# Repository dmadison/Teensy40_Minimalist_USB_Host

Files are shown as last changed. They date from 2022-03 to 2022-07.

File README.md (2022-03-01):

# Teensy 4.0 Minimalist USB Host Shield

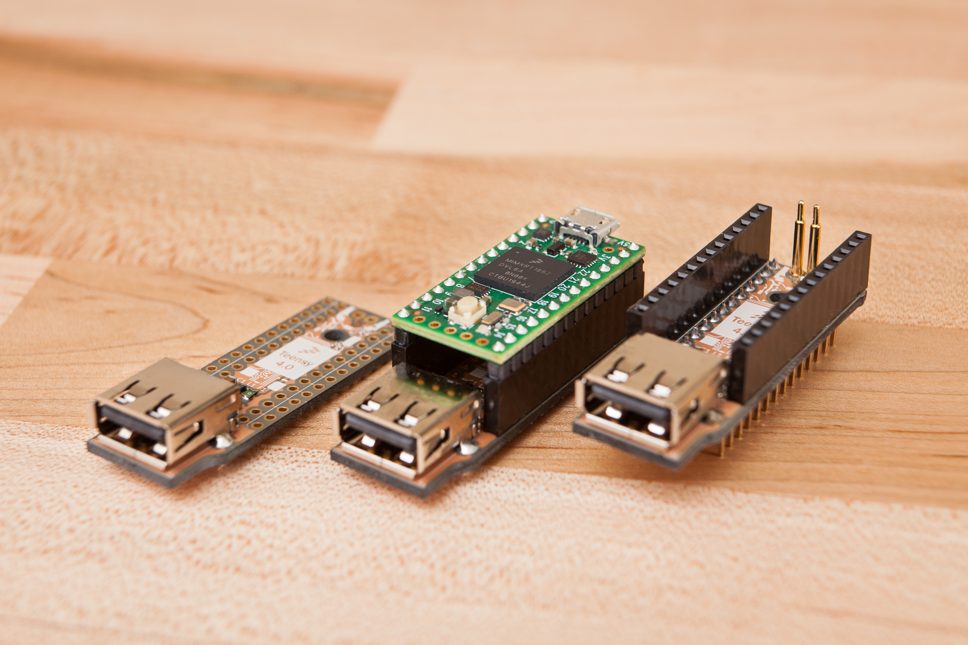
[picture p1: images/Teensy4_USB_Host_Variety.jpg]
Variations of the Teensy 4.0 Minimalist USB Host Shield, v1.0.0


This repository contains the KiCAD 6 board files for the [Teensy 4.0 minimalist USB host shield](https://www.partsnotincluded.com/teensy-4-0-minimalist-usb-host-shield). The shield is designed to connect to the underside of the Teensy 4.0 board and provide a safe and stable USB-A host port in a small and lightweight size.

The Teensy board needs to be soldered to 0.1" male headers. It can then be mated to the shield with 0.1" female headers and pogo pins, or soldered directly using enamel wire to connect to the data pads on the underside of the board.

For pogo pins, see the [PJRC Teensy 4.0 breakout board](https://www.pjrc.com/breakout-board-for-teensy-4-0/) page for reference. For my own boards I used 12 mm pogo pins purchased from RTLECS on AliExpress.

Generated gerbers and bill of materials can be found on the [releases](../../releases/latest) page.

## License

The KiCAD project files including the schematic, PCB design, symbols, and most footprints are released in the public domain with no rights reserved.

The [Parts Not Included](https://www.partsnotincluded.com/) logo, included on the bottom of the shield, is copyrighted. It may be reproduced as a silkscreen graphic in this project and its derivatives without modification.

Included images are licensed under the [CC BY-NC-ND 4.0 license](https://creativecommons.org/licenses/by-nc-nd/4.0/). Attribution should be to Dave Madison ([@dmadison](https://github.com/dmadison)).

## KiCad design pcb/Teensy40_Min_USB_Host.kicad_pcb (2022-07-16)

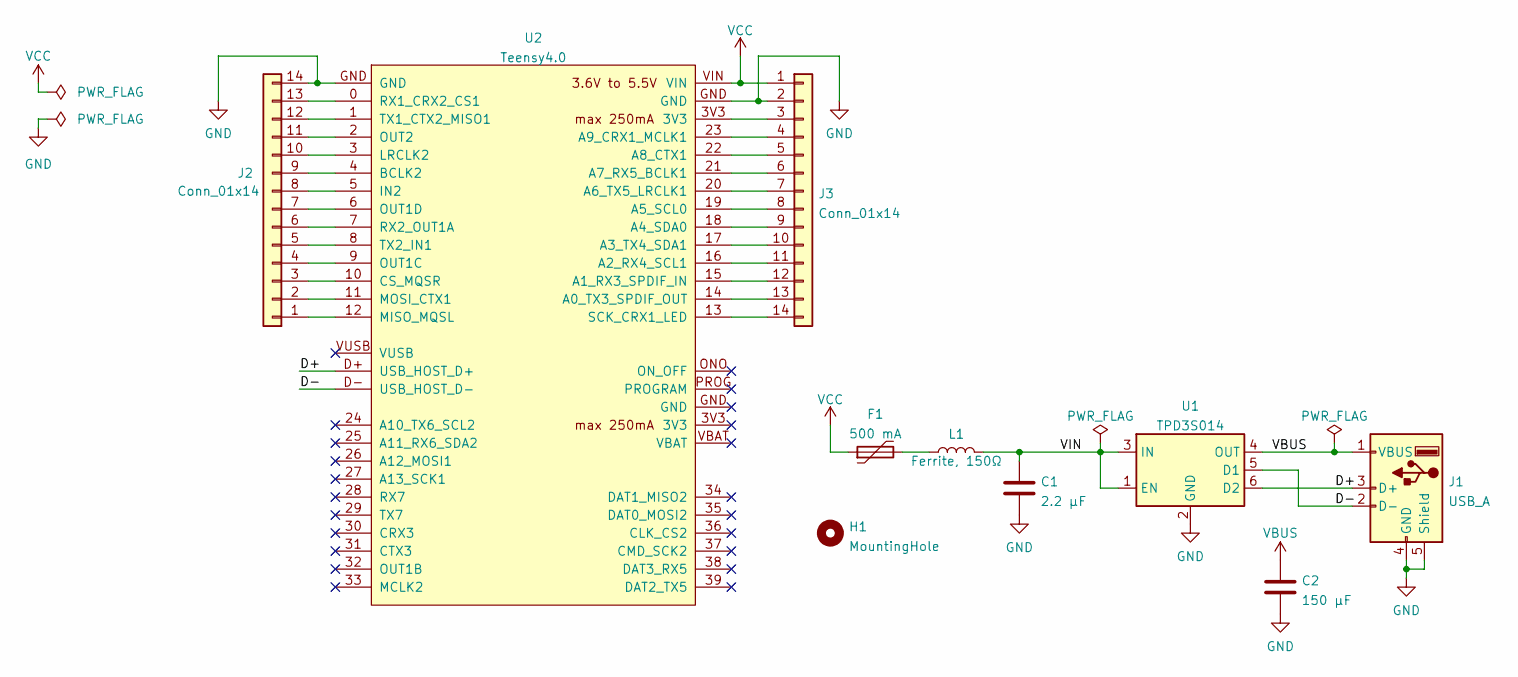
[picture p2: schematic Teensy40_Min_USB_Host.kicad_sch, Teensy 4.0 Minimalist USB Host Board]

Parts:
C1: 2.2 µF; C_0805_2012Metric; DigiKey Product Number 445-1420-1-ND - Cut Tape
C2: 150 µF; CP_EIA-3216-10_Kemet-I; DigiKey Product Number 478-6250-1-ND
F1: 500 mA; Fuse_0805_2012Metric; DigiKey Product Number 283-PTS08056V050CT-ND
H1: MountingHole; MountingHole_3.2mm
J1: USB_A; USB_A_Stewart_SS-52100-001_Horizontal; DigiKey Product Number 380-1412-ND
J2, J3: Conn_01x14; PinHeader_1x14_P2.54mm_Vertical; DigiKey Product Number S1011EC-14-ND
L1: Ferrite, 150Ω; L_0805_2012Metric; DigiKey Product Number MH2029-151YCT-ND
U1: TPD3S014; SOT-23-6; DigiKey Product Number 296-44163-1-ND
U2: Teensy4.0; Teensy40_USB; DigiKey Product Number 1568-DEV-15583-ND

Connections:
/D+: J1.3 (D+), U1.6 (D2), U2.D+ (USB_HOST_D+)
/D-: J1.2 (D-), U1.5 (D1), U2.D- (USB_HOST_D-)
/VIN: C1.1, L1.2, U1.1 (EN), U1.3 (IN)
GND: C1.2, C2.2, J1.4 (GND), J1.5 (Shield), J2.14, J3.2, U1.2 (GND), U2.GND
unnamed: F1.2, L1.1
unnamed: J2.1, U2.12 (MISO_MQSL)
unnamed: J2.2, U2.11 (MOSI_CTX1)
unnamed: J2.3, U2.10 (CS_MQSR)
unnamed: J2.4, U2.9 (OUT1C)
unnamed: J2.5, U2.8 (TX2_IN1)
unnamed: J2.6, U2.7 (RX2_OUT1A)
unnamed: J2.7, U2.6 (OUT1D)
unnamed: J2.8, U2.5 (IN2)
unnamed: J2.9, U2.4 (BCLK2)
unnamed: J2.10, U2.3 (LRCLK2)
unnamed: J2.11, U2.2 (OUT2)
unnamed: J2.12, U2.1 (TX1_CTX2_MISO1)
unnamed: J2.13, U2.0 (RX1_CRX2_CS1)
unnamed: J3.3, U2.3V3
unnamed: J3.4, U2.23 (A9_CRX1_MCLK1)
unnamed: J3.5, U2.22 (A8_CTX1)
unnamed: J3.6, U2.21 (A7_RX5_BCLK1)
unnamed: J3.7, U2.20 (A6_TX5_LRCLK1)
unnamed: J3.8, U2.19 (A5_SCL0)
unnamed: J3.9, U2.18 (A4_SDA0)
unnamed: J3.10, U2.17 (A3_TX4_SDA1)
unnamed: J3.11, U2.16 (A2_RX4_SCL1)
unnamed: J3.12, U2.15 (A1_RX3_SPDIF_IN)
unnamed: J3.13, U2.14 (A0_TX3_SPDIF_OUT)
unnamed: J3.14, U2.13 (SCK_CRX1_LED)
VBUS: C2.1, J1.1 (VBUS), U1.4 (OUT)
VCC: F1.1, J3.1, U2.VIN

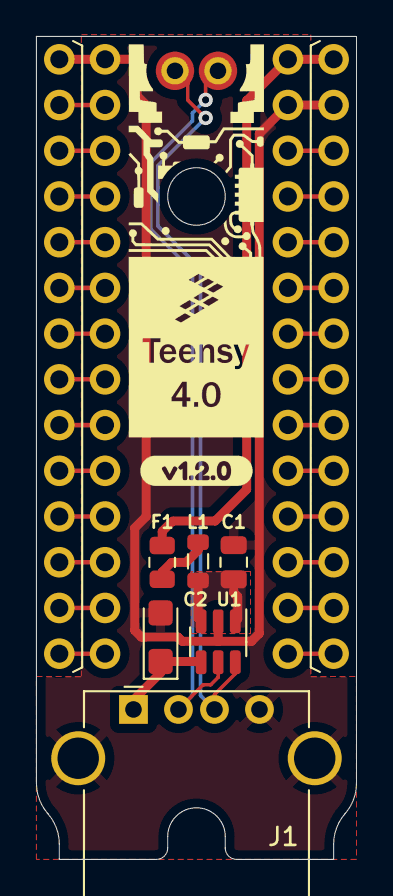
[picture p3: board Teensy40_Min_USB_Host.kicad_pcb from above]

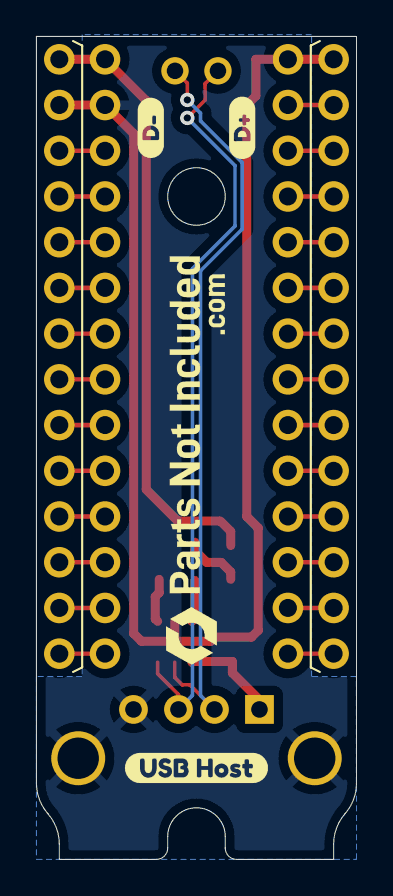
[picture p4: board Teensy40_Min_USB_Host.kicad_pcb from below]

Board: 2 copper layers, 17.8 x 45.7 mm, 14 parts (5 on the bottom side), 32 nets.

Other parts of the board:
kibuzzard-61E338B9: G***; kibuzzard-61E338B9
kibuzzard-61E3388A: G***; kibuzzard-61E3388A
kibuzzard-621DEA3B: G***; kibuzzard-621DEA3B
kibuzzard-628AF6F2: G***; kibuzzard-628AF6F2

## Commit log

2022-03-01 Change fuse footprint
    Use the proper 0805 fuse footprint instead of the 0805 inductor footprint.
    [Teensy40_Min_USB_Host.kicad_pcb, Teensy40_Min_USB_Host.kicad_sch]
2022-03-01 Move board edge back by 0.2"
    Allows space for the USB-A port to integrate into a panel or case.
    With the smaller size, the alignment hole at the USB-A port has been moved to make a half-circle cut at the board edge. This changes the distance between alignment holes from 1.4" to 1.45".
    [Teensy40_Min_USB_Host.kicad_pcb]
2022-03-01 Move alignment hole back to original position
    This makes the alignment hole position and distance (1.4") the same between v1.0.0 and v1.1.0. For what that's worth.
    [Teensy40_Min_USB_Host.kicad_pcb]
2022-03-01 Add board version to README image alt tag
2022-05-23 Remove lower portion of Teensy circuit silkscreen
    Making some extra space for the version label, so it's not covered by the USB port.
    [Teensy40_Min_USB_Host.kicad_pcb]
2022-05-23 Update version footprint to 1.2.0
    This is also now positioned underneath the Teensy instead of underneath the USB port, for visibility whenever the circuit is fully soldered.
    [Teensy40_Min_USB_Host.kicad_pcb]
2022-05-23 Replace C2 cap with tantalum, 150 uF
    Having some suspected brownout issues with rumble motors using the 100 uF ceramic cap, and I found some documentation from TI that says the USB host output capacitance should be 120 µF at a minimum.
    [Teensy40_Min_USB_Host.kicad_pcb, Teensy40_Min_USB_Host.kicad_sch]
2022-05-23 Update Teensy schematic symbol from lib
    I forgot to update the schematic after updating the library. Committing now to satisfy the ERC check.
    [Teensy40_Min_USB_Host.kicad_sch]
2022-05-23 Add VBUS label to schematic
    Better than using a local label standalone.
    [Teensy40_Min_USB_Host.kicad_pcb, Teensy40_Min_USB_Host.kicad_sch]
2022-05-23 Remove H2 mounting hole
    This semi-circle is now part of the board outline, and the radius (1.6 mm) is large enough for most board houses that a separate drill is not needed.
    [Teensy40_Min_USB_Host.kicad_pcb, Teensy40_Min_USB_Host.kicad_sch]
2022-05-23 Shorten and arrange all silkscreen refs
    Making these slightly smaller (0.8 -> 0.7) and aligned straight, both with their components and with each-other.
    [Teensy40_Min_USB_Host.kicad_pcb]
2022-05-23 Add gerbers folder to gitignore
    Gerbers are published with GitHub releases
2022-05-23 Flip current limiter horizontal positions
    This provides much better routing of the VBUS net, which can go directly between U1 and C2 instead of having to route around the USB port pins.
    [Teensy40_Min_USB_Host.kicad_pcb]
2022-05-23 Center current limiting circuit block
    "Center" being a rough estimate.
    Man these are huge diffs for such a minor change... those filled zones are no joke.
    [Teensy40_Min_USB_Host.kicad_pcb]
2022-07-13 Fix PCB edge cut grouping
    Remove redundant groups and add second hole cutout segments.
    [Teensy40_Min_USB_Host.kicad_pcb]
2022-07-13 Fix malformed board edge fillet
    These curves were not continuous, which created a crossover artifact where they met. This wasn't flagged as an issue because the board area is technically fully enclosed.
    This commit fixes the curve so it's smooth. Note that my 1.2 boards manufactured by OSH Park turned out fine with the malformed edge, so this is mostly just a design-space issue.
    [Teensy40_Min_USB_Host.kicad_pcb]
